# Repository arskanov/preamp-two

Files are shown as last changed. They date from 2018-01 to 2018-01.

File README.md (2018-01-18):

# Headphone Amp + Preamp

This project is based on "preamp two" from Max Williams. It has the following features:

  * A precision volume control using a R2R multiplying DAC
  * 3 input selector with mute
  * Dedicated headphone preamp for heavier loads
  * Volume and input control via rotary encoders and an ESP32.
  * Start-up mute.

All together 1

All together 2

## Hardware

### MDAC attenuator

Based on a design from a Analog Devices circuit note: http://www.analog.com/en/design-center/reference-designs/hardware-reference-design/circuits-from-the-lab/CN0025.html

This design is also used by a number manufacturers.

  * 65536 linear steps (16bit)
  * Any gain possible, set by OPAMP and resistors
  * Excellent performance
  * Can drive headphones
  * Compact
  * SPI controlled

MDAC attenuator 1

MDAC attenuator 2

### Input selector

  * 6x inputs
  * Mute for the output
  * SPI controlled using a MCP23S17
  * Latching relays so no constant current draw (mute is not latching, obviously)
  * Uses high quality Panasonic GQ relays (AGQ)

Input selector 1

Input selector 2

### RCA board

Designed for [CMC 816 RCA](http://www.audio-cmc.com/rca-jacks/rca-jacks-p_29.html) sockets, they can be soldered directly on to the PCB and are easy to find on eBay or Aliexpress etc.

RCA board 1

RCA board 2

### Infrared remote control

The IRremote library is from here:
https://github.com/z3t0/Arduino-IRremote

## Bill of materials

### Input selector

| Part name | Farnell Part | Detail | Description | Notes | Quantity |
|---|---|---|---|---|---|
| K1-6 | 1867255 | AGQ2104H | 1 coil latching | | 6 |
| KMUTE | 3104813 | AGQ2004H | Single side stable | | 1 |
| IC1 | - | MCP23S17SO | | | 1 |
| IC2, IC3 | - | ULN2803 | | | 2 |
| R1-12 | - | | 47R, 1206 | | 12 |
| EXTRA_IO | 1675765 | MULTICOMP MC34631 Wire-To-Board Connector, Vertical, MC34 Series, Through Hole, Header, 3, 2.54 mm | | | 1 |
| X1 | 1675768 | MULTICOMP MC34635 Wire-To-Board Connector, MC34 Series, Through Hole, Header, 6, 2.54 mm, Tin Plated Contacts | | | 1 |
| POWER | 1675764 | MULTICOMP MC34629 Wire-To-Board Connector, Vertical, MC34 Series, Through Hole, Header, 2, 2.54 mm | | | 1 |
| IN1-6, SEL_OUT, MUTE_IN, MUTE_OUT | 1675765 | MULTICOMP MC34631 Wire-To-Board Connector, Vertical, MC34 Series, Through Hole, Header, 3, 2.54 mm | | | 9 |
| C2 | - | Panasonic E/D SMD (8/6.3mm) or 3.5/8mm leaded | | | 1 |
| C1 | 1414725 | KEMET - C1206C224K5RACTU | | | 1 |
| LED | 2217976 | 1206 LED | | | 1 |
| RLED | - | 1206 Resistor, 1.2K | | | 1 |

### MDAC attenuator

To calculate gain use this formula:

      gain = (R2+R3)/R2
      R1 = (R2*R3)/(R2+R3)

This was copied from the [AD5429/AD5439/AD5449 datasheet](http://www.analog.com/media/en/technical-documentation/data-sheets/AD5429_5439_5449.pdf)

| Part name | Farnell Part | Detail | Description | Notes | Quantity |
|---|---|---|---|---|---|
| U2 | 1390687 | TI DAC8812ICPWG4 | | | 1 |
| IC2 | 1438872 | ANALOG DEVICES - AD8599ARZ | Description: IC, OP AMP, DUAL, SMD, SOIC8, 8599  | | 1 |
| C1A, C1B | 1759181 | MULTICOMP - MCCA000310 | Description: CAP, MLCC, C0G/NP0, 2PF, 50V, 0805  | | 2 |
| R1A/B | 1841733 | PANASONIC - ERA8AEB910V | Description: RESISTOR, 1206, 0.1%, 0.25W, 91R | 91R (gain of 4)  | 2 |
| R2A/B, R4A/B | 1841735 | PANASONIC - ERA8AEB121V | Description: RESISTOR, 1206, 0.1%, 0.25W, 120R | 120R (gain of 4) | 4 |
| R3A/B | 1841744 | PANASONIC - ERA8AEB361V | Description: RESISTOR, 1206, 0.1%, 0.25W, 360R | 360R (gain of 4) | 2 |
| C7 | - | - | Panasonic D/C SMD (6.3/5mm) or 3.5/8mm leaded | | 1 |
| C6, C6 | - | - | Panasonic E/D SMD (8/6.3mm) or 3.5/8mm leaded | | 2 |
| X1 | 1675777 | MULTICOMP MC34649 | Description: HEADER, THT, VERTICAL, 2.54MM, 6WAY | | 1 |
| IN, OUT, PWR | 1675765 | MULTICOMP - MC34631 | Description: HEADER, THT, VERTICAL, 2.54MM, 3WAY | | 3 |
| C2, C3, C4 | 1414725 | KEMET - C1206C224K5RACTU | Description: CAP, MLCC, X7R, 220NF, 50V, 1206 | | 3 |
| LED | 2217976 | 1206 LED | Description: LED, SMD, 1206 BLUE | | 1 |
| RLED | - | 1206 Resistor, 1.2K | | | 1 |

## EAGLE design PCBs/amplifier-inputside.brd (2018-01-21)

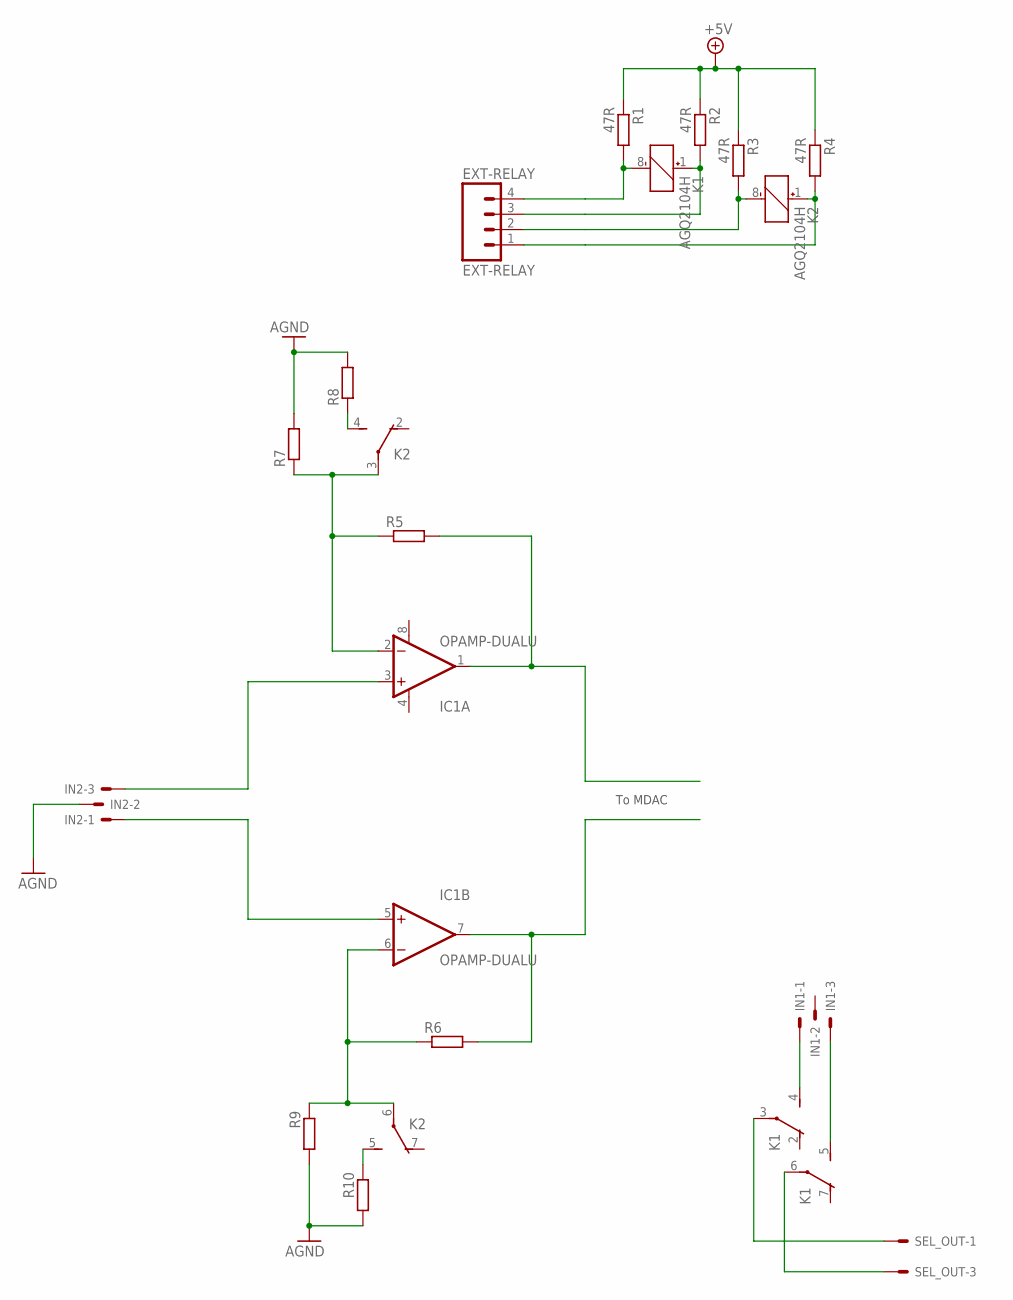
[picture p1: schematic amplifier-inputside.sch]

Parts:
EXT-RELAY: EXT-RELAY; MOLEX-1X4
IC1: OPAMP-DUALU; SO08
IN1, IN2: 22-23-2031
K1, K2: AGQ2104H; PCBBOARD
R1, R2, R3, R4: 47R; R1206
R5, R6, R7, R8, R9, R10: R-EU_R1206W; R1206W
SEL_OUT: 22-23-2031

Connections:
+5V: R1.1, R2.1, R3.1, R4.1
AGND: IN2.2, R7.2, R8.2, R9.2, R10.2
INL: K1.3, SEL_OUT.1
INR: K1.6, SEL_OUT.3
unnamed: IN1.1, K1.4 (S)
unnamed: IC1.3 (+IN), IN2.3
unnamed: IN1.3, K1.5 (S)
unnamed: IC1.5 (+IN), IN2.1
unnamed: K1.8 (-), R1.2
unnamed: K2.4 (S), R8.1
unnamed: IC1.1 (OUT), R5.2
unnamed: K1.1 (+), R2.2
unnamed: K2.8 (-), R3.2
unnamed: IC1.7 (OUT), R6.2
unnamed: K2.1 (+), R4.2
unnamed: IC1.2 (-IN), K2.3, R5.1, R7.1
unnamed: K2.5 (S), R10.1
unnamed: IC1.6 (-IN), K2.6, R6.1, R9.1
V+: IC1.8 (V+)
V-: IC1.4 (V-)

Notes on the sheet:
To MDAC

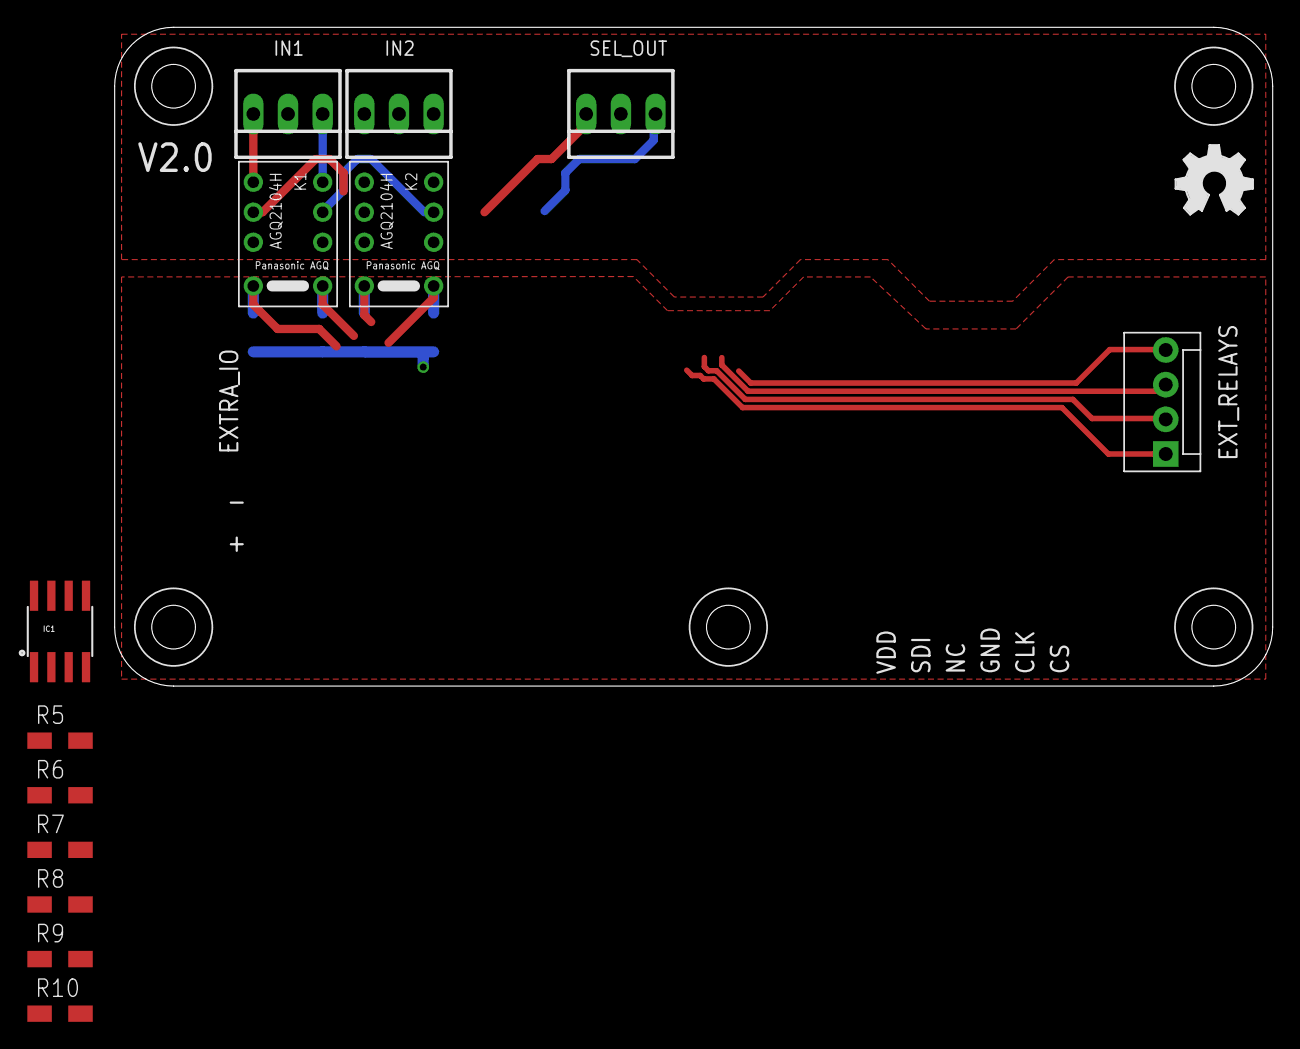
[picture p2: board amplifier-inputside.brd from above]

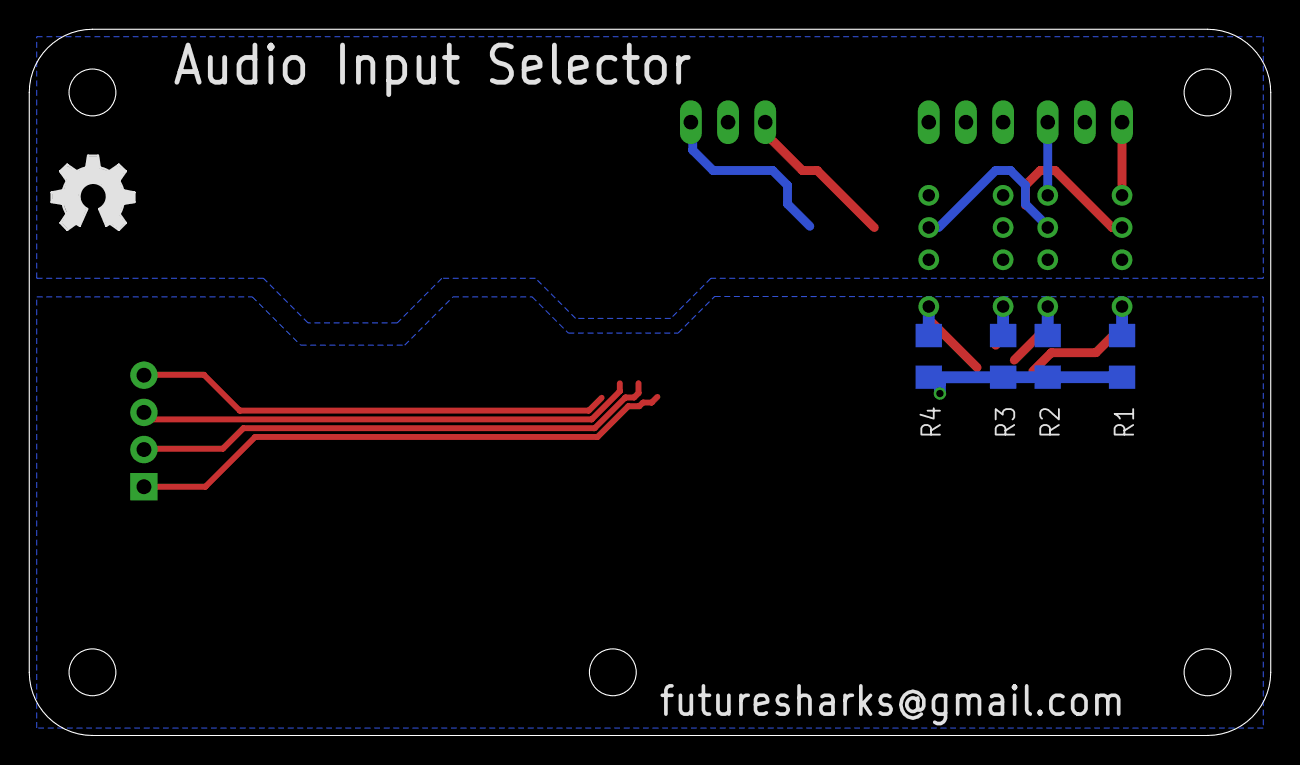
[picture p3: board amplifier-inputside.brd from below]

Board: 2 copper layers, 84.8 x 48.3 mm, 24 parts (5 on the bottom side), 18 nets.

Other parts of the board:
LOGO1, LOGO2: OSHW_LOGO_FILLX0200-NT; OSHW_FILLX200_NOTEXT
U$1, U$2, U$3, U$4, U$5: M3_HOLE

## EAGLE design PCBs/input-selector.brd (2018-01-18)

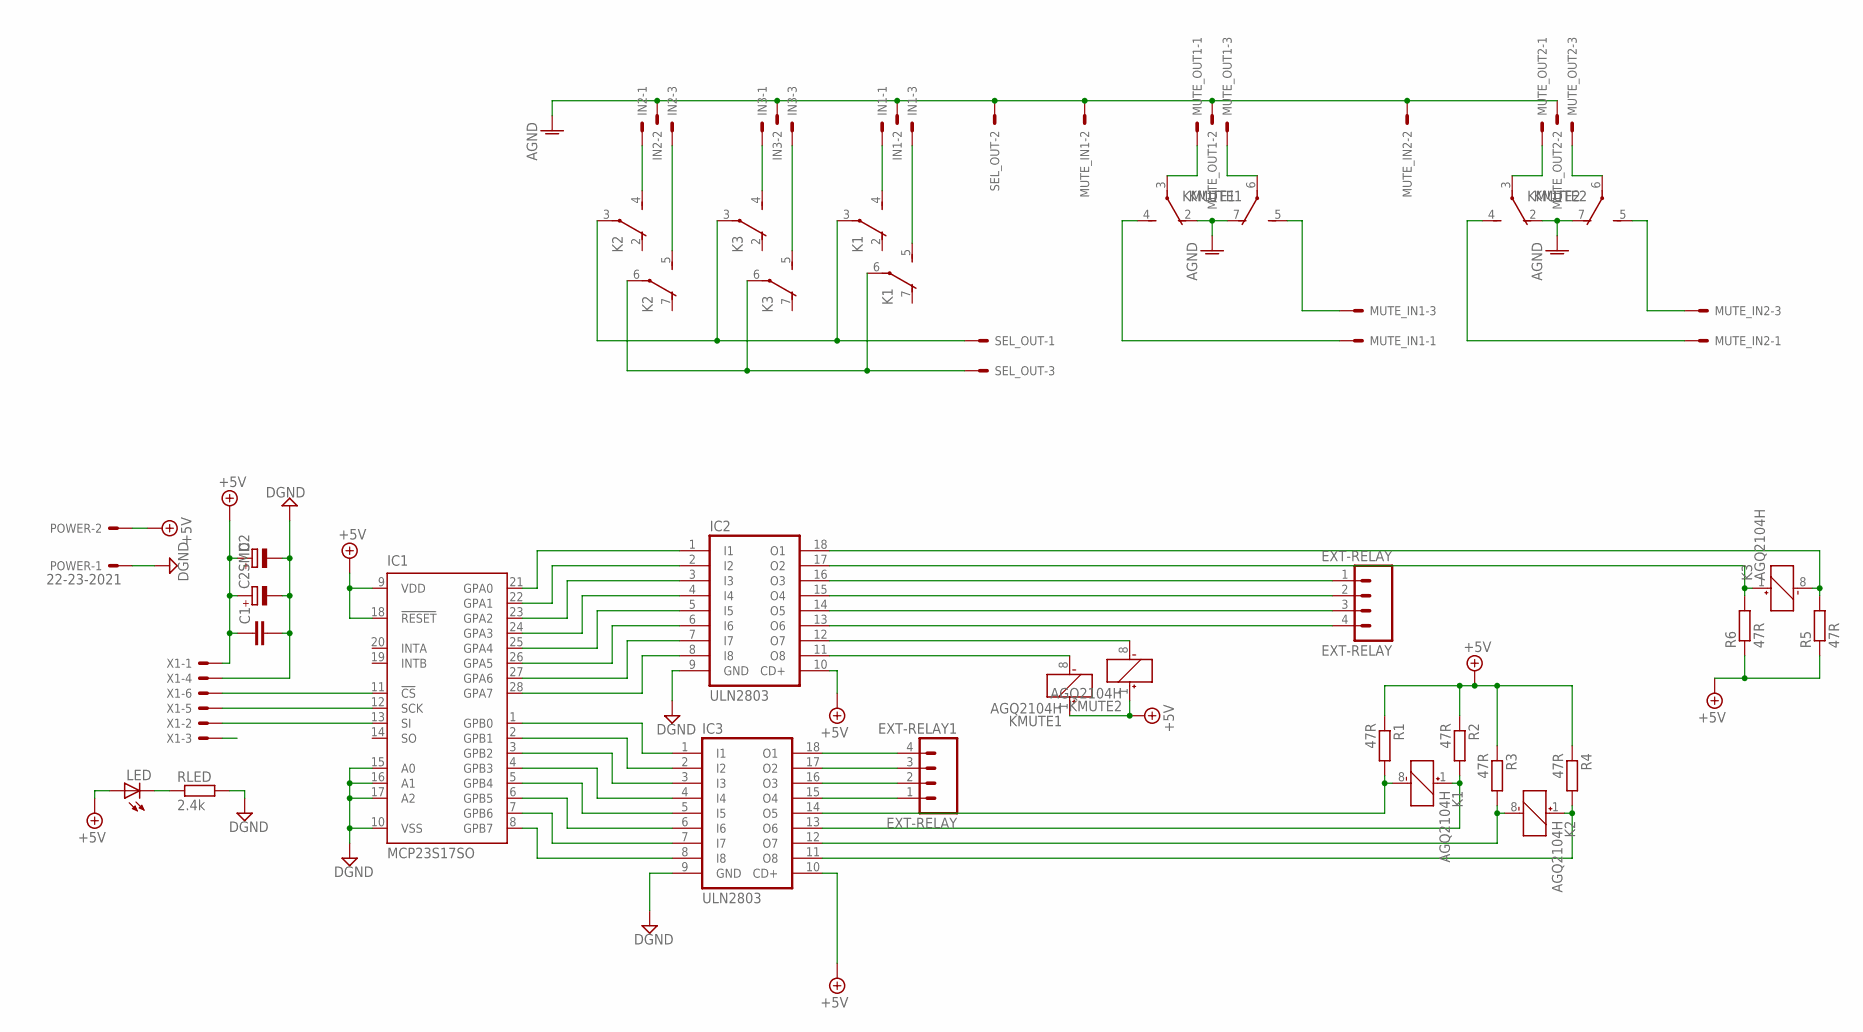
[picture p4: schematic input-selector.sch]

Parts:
C1: C-EUC1206; C1206
C2: CPOL-EUE3.5-8; E3,5-8
C2SMD: CPOL-EUE; PANASONIC_E
EXT-RELAY, EXT-RELAY1: EXT-RELAY; MOLEX-1X4
IC1: MCP23S17SO; SO28W
IC2, IC3: ULN2803; SO-18W
IN1, IN2, IN3: 22-23-2031
K1, K2, K3: AGQ2104H; PCBBOARD
KMUTE1, KMUTE2: AGQ2104H; PCBBOARD
LED: LEDSMT1206; 1206
MUTE_IN1, MUTE_IN2: 22-23-2031
MUTE_OUT1, MUTE_OUT2: 22-23-2031
POWER: 22-23-2021
R1, R2, R3, R4, R5, R6: 47R; R1206
RLED: 2.4k; R1206
SEL_OUT: 22-23-2031
X1: 22-23-2061

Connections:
+5V: C1.1, C2.+, C2SMD.+, IC1.9 (VDD), IC1.18 (!RESET), IC2.10 (CD+), IC3.10 (CD+), KMUTE1.1 (+), KMUTE2.1 (+), LED.A, POWER.2, R1.1, R2.1, R3.1, R4.1, R5.1, R6.1, X1.1
AGND: IN1.2, IN2.2, IN3.2, KMUTE1.2 (O), KMUTE1.7 (O), KMUTE2.2 (O), KMUTE2.7 (O), MUTE_IN1.2, MUTE_IN2.2, MUTE_OUT1.2, MUTE_OUT2.2, SEL_OUT.2
CLK: IC1.12 (SCK), X1.5
CS: IC1.11 (!CS), X1.6
DGND: C1.2, C2.-, C2SMD.-, IC1.10 (VSS), IC1.15 (A0), IC1.16 (A1), IC1.17 (A2), IC2.9 (GND), IC3.9 (GND), POWER.1, RLED.2, X1.4
INL: K1.3, K2.3, K3.3, SEL_OUT.1
INR: K1.6, K2.6, K3.6, SEL_OUT.3
unnamed: IN1.1, K1.4 (S)
unnamed: EXT-RELAY1.1, IC3.15 (O4)
unnamed: IN1.3, K1.5 (S)
unnamed: EXT-RELAY1.2, IC3.16 (O3)
unnamed: IC3.14 (O5), K1.8 (-), R1.2
unnamed: IC2.11 (O8), KMUTE1.8 (-)
unnamed: IC1.21 (GPA0), IC2.1 (I1)
unnamed: IC3.13 (O6), K1.1 (+), R2.2
unnamed: IC3.12 (O7), K2.8 (-), R3.2
unnamed: EXT-RELAY1.3, IC3.17 (O2)
unnamed: EXT-RELAY.1, IC2.16 (O3)
unnamed: IC3.11 (O8), K2.1 (+), R4.2
unnamed: EXT-RELAY1.4, IC3.18 (O1)
unnamed: IC2.18 (O1), K3.8 (-), R5.2
unnamed: EXT-RELAY.2, IC2.15 (O4)
unnamed: EXT-RELAY.4, IC2.13 (O6)
unnamed: KMUTE1.6, MUTE_OUT1.3
unnamed: KMUTE1.3, MUTE_OUT1.1
unnamed: IC2.12 (O7), KMUTE2.8 (-)
unnamed: KMUTE2.6, MUTE_OUT2.3
unnamed: IC1.23 (GPA2), IC2.3 (I3)
unnamed: IC2.17 (O2), K3.1 (+), R6.2
unnamed: EXT-RELAY.3, IC2.14 (O5)
unnamed: KMUTE2.3, MUTE_OUT2.1
unnamed: IN2.1, K2.4 (S)
unnamed: IN2.3, K2.5 (S)
unnamed: IN3.1, K3.4 (S)
unnamed: IN3.3, K3.5 (S)
unnamed: IC1.25 (GPA4), IC2.5 (I5)
unnamed: IC1.27 (GPA6), IC2.7 (I7)
unnamed: IC1.1 (GPB0), IC3.1 (I1)
unnamed: IC1.2 (GPB1), IC3.2 (I2)
unnamed: IC1.3 (GPB2), IC3.3 (I3)
unnamed: IC1.4 (GPB3), IC3.4 (I4)
unnamed: IC1.5 (GPB4), IC3.5 (I5)
unnamed: IC1.6 (GPB5), IC3.6 (I6)
unnamed: IC1.7 (GPB6), IC3.7 (I7)
unnamed: IC1.8 (GPB7), IC3.8 (I8)
unnamed: IC1.22 (GPA1), IC2.2 (I2)
unnamed: IC1.24 (GPA3), IC2.4 (I4)
unnamed: IC1.26 (GPA5), IC2.6 (I6)
unnamed: IC1.28 (GPA7), IC2.8 (I8)
unnamed: LED.C, RLED.1
NC: X1.3
OUTL: KMUTE1.4 (S), MUTE_IN1.1
OUTL1: KMUTE2.4 (S), MUTE_IN2.1
OUTR: KMUTE1.5 (S), MUTE_IN1.3
OUTR1: KMUTE2.5 (S), MUTE_IN2.3
SDI: IC1.13 (SI), X1.2

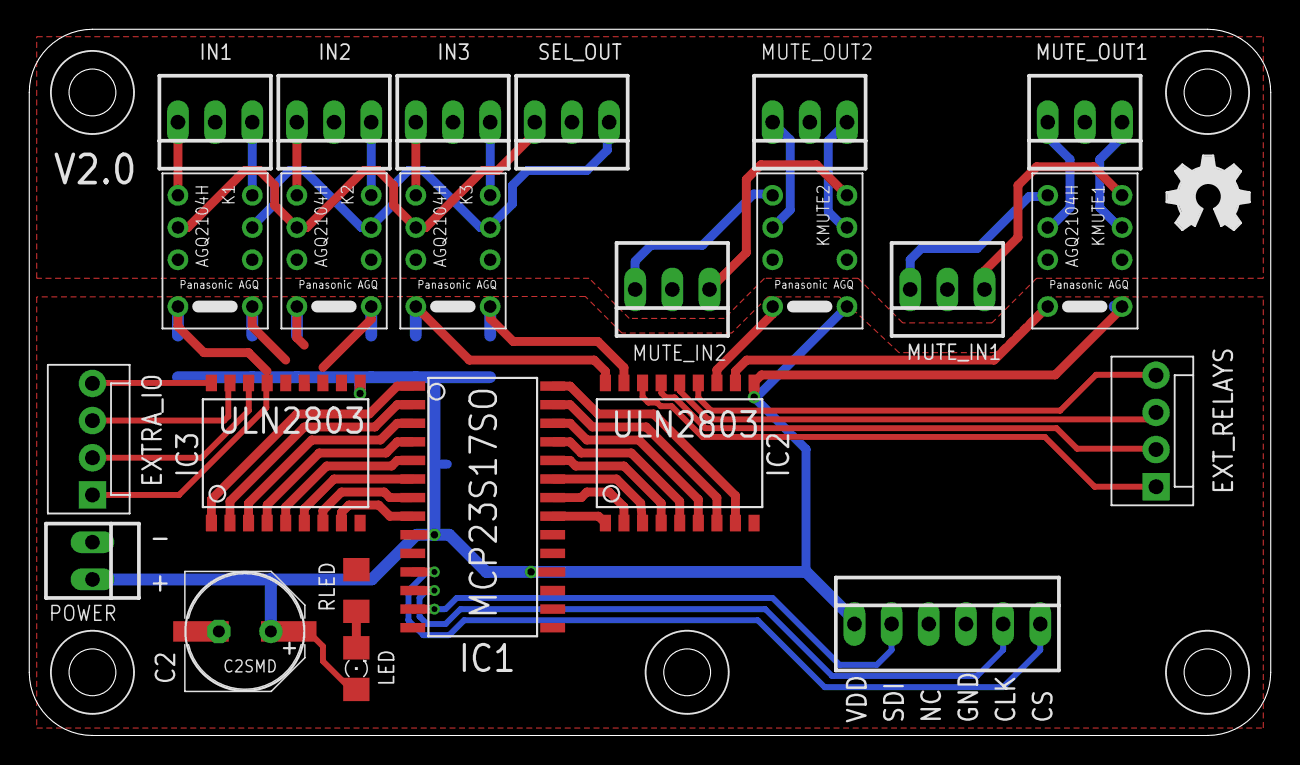
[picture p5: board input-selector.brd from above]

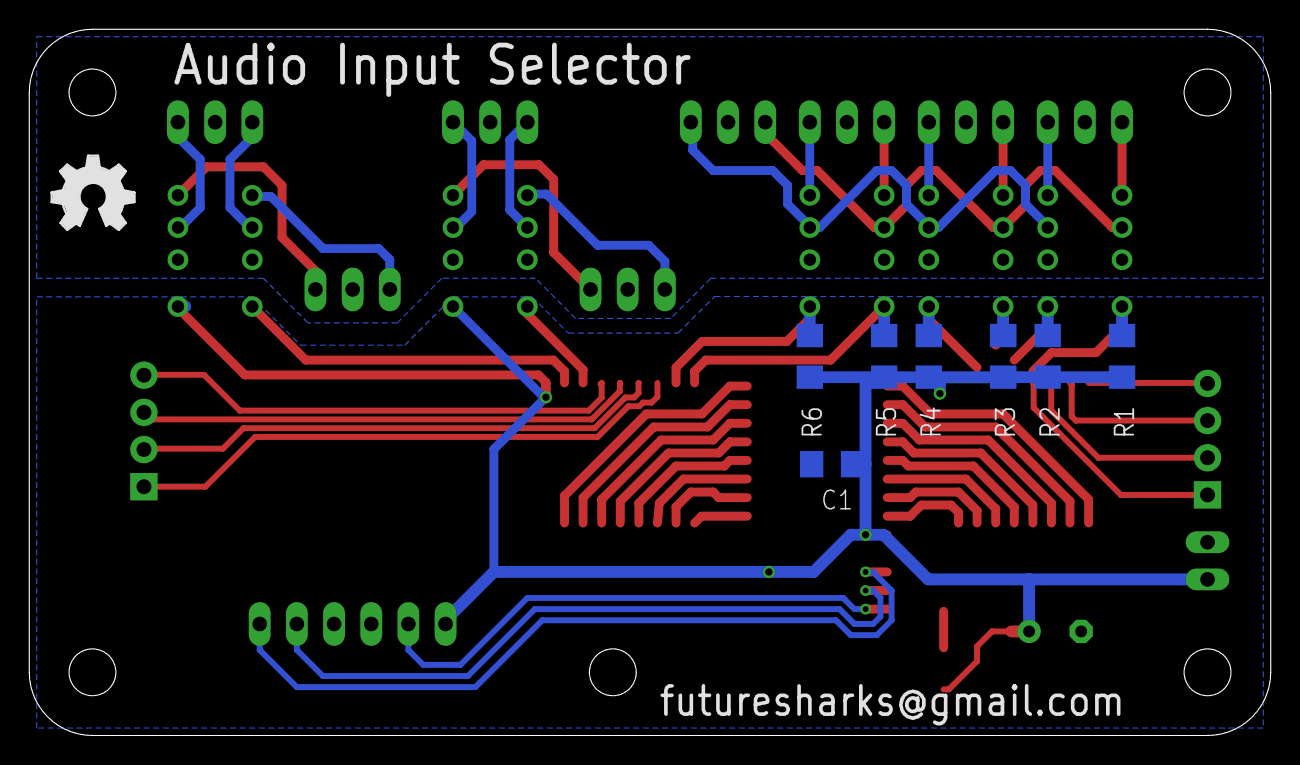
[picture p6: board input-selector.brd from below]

Board: 2 copper layers, 84.8 x 48.3 mm, 38 parts (8 on the bottom side), 55 nets.

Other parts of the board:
LOGO1, LOGO2: OSHW_LOGO_FILLX0200-NT; OSHW_FILLX200_NOTEXT
U$1, U$2, U$3, U$4, U$5: M3_HOLE

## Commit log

2018-01-18 Initial commit with first changes
    [input-selector.brd, input-selector.sch]
2018-01-18 Finished up connections
    [input-selector.brd, input-selector.sch]
2018-01-21 Added amplifier's input side gain switch
    [amplifier-inputside.brd, amplifier-inputside.sch]

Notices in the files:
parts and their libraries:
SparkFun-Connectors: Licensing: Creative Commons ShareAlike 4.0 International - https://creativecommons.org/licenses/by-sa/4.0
